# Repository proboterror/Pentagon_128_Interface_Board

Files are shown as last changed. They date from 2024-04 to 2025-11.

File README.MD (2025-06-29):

# Интерфейсная плата разъемов для Pentagon 128 2023/2024

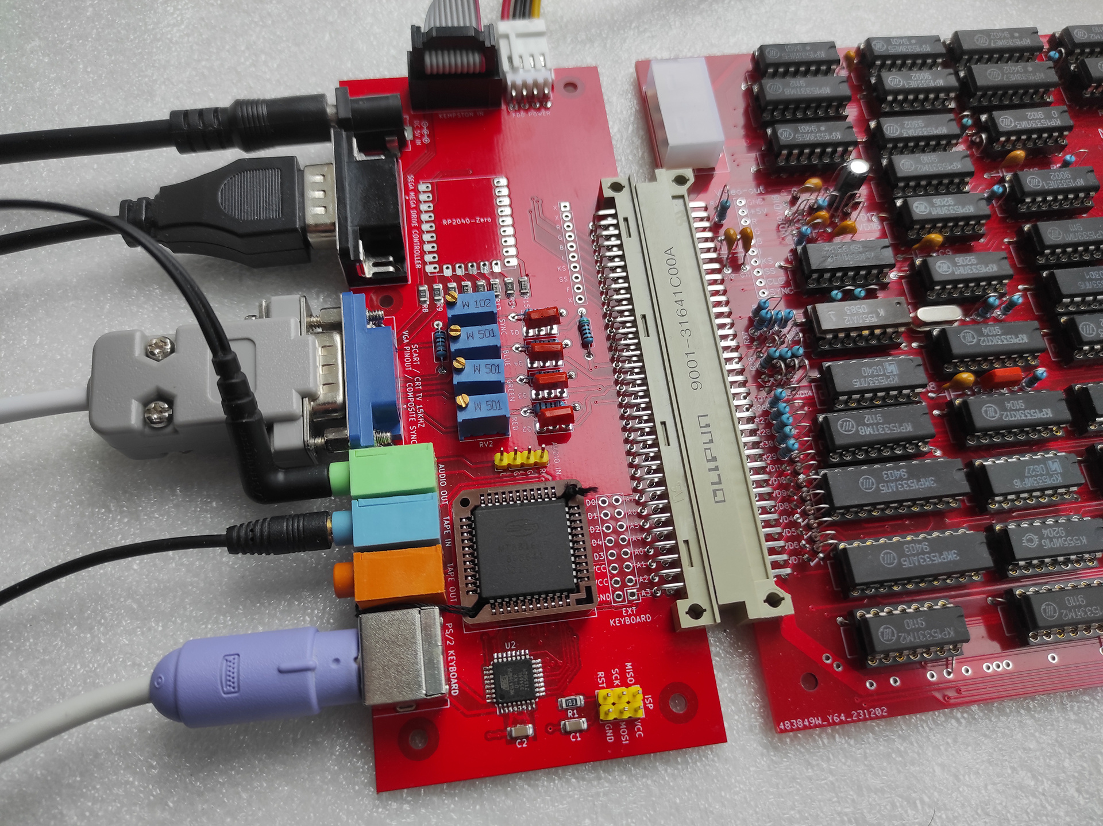
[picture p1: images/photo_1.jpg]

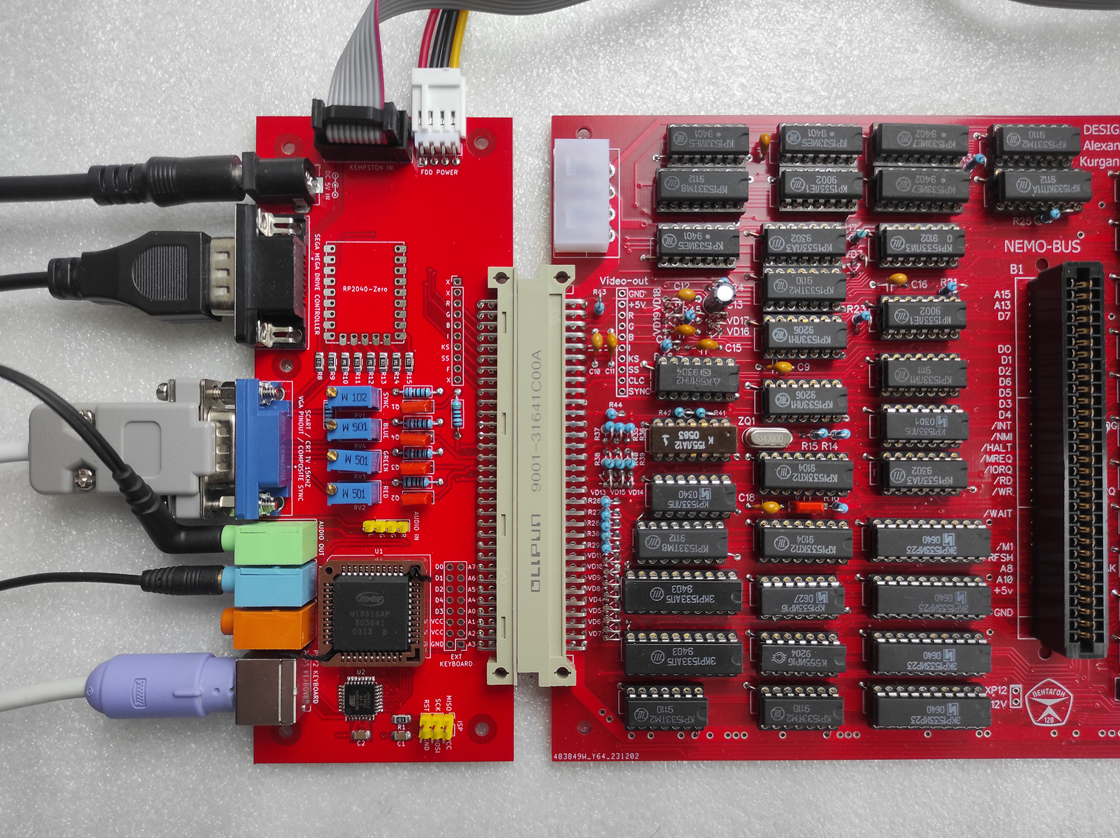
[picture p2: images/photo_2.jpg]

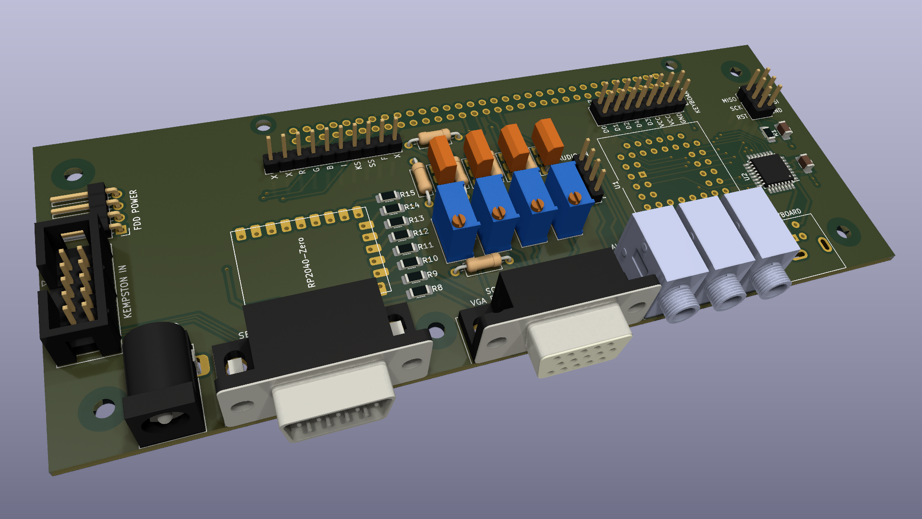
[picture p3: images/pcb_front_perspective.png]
pcb_front_perspective

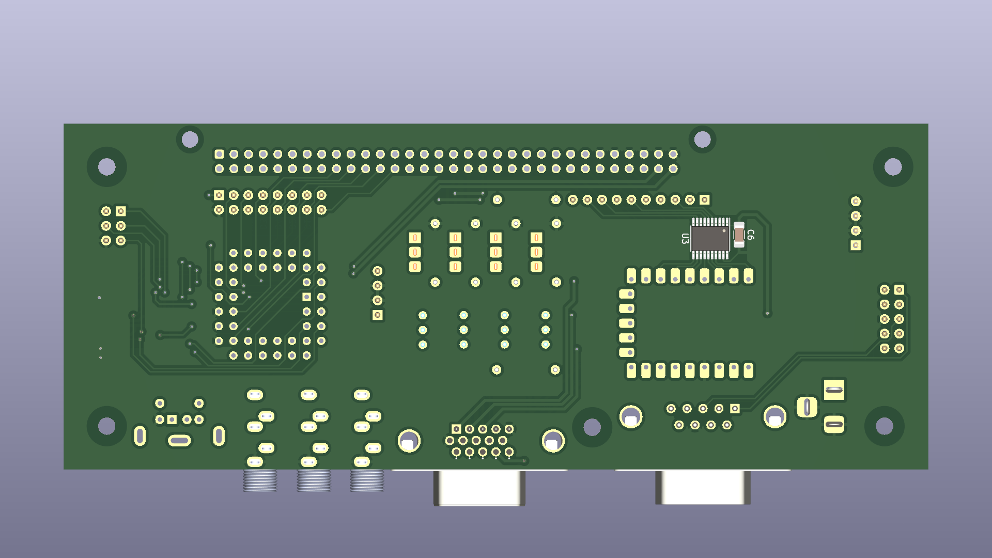
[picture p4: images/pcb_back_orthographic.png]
pcb_back_orthographic

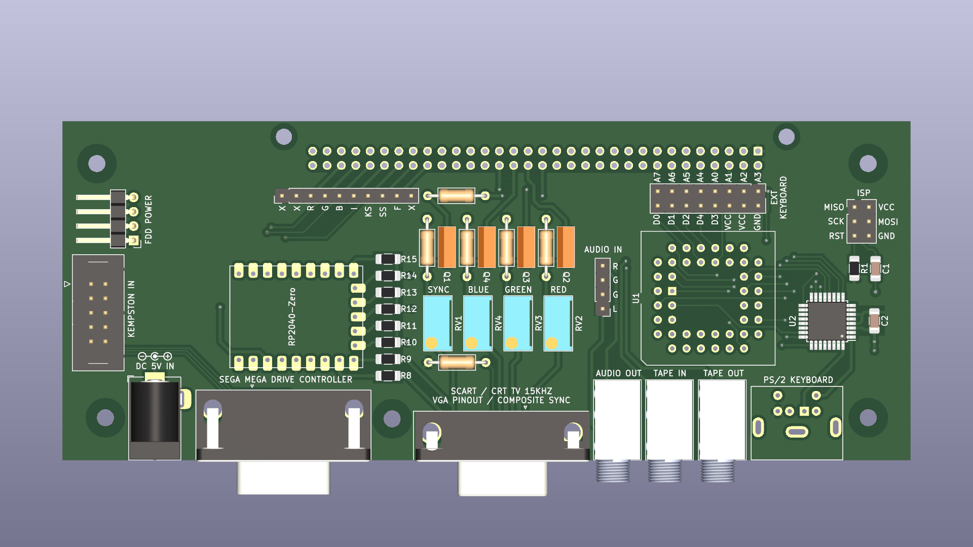
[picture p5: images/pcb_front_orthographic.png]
pcb_front_orthographic

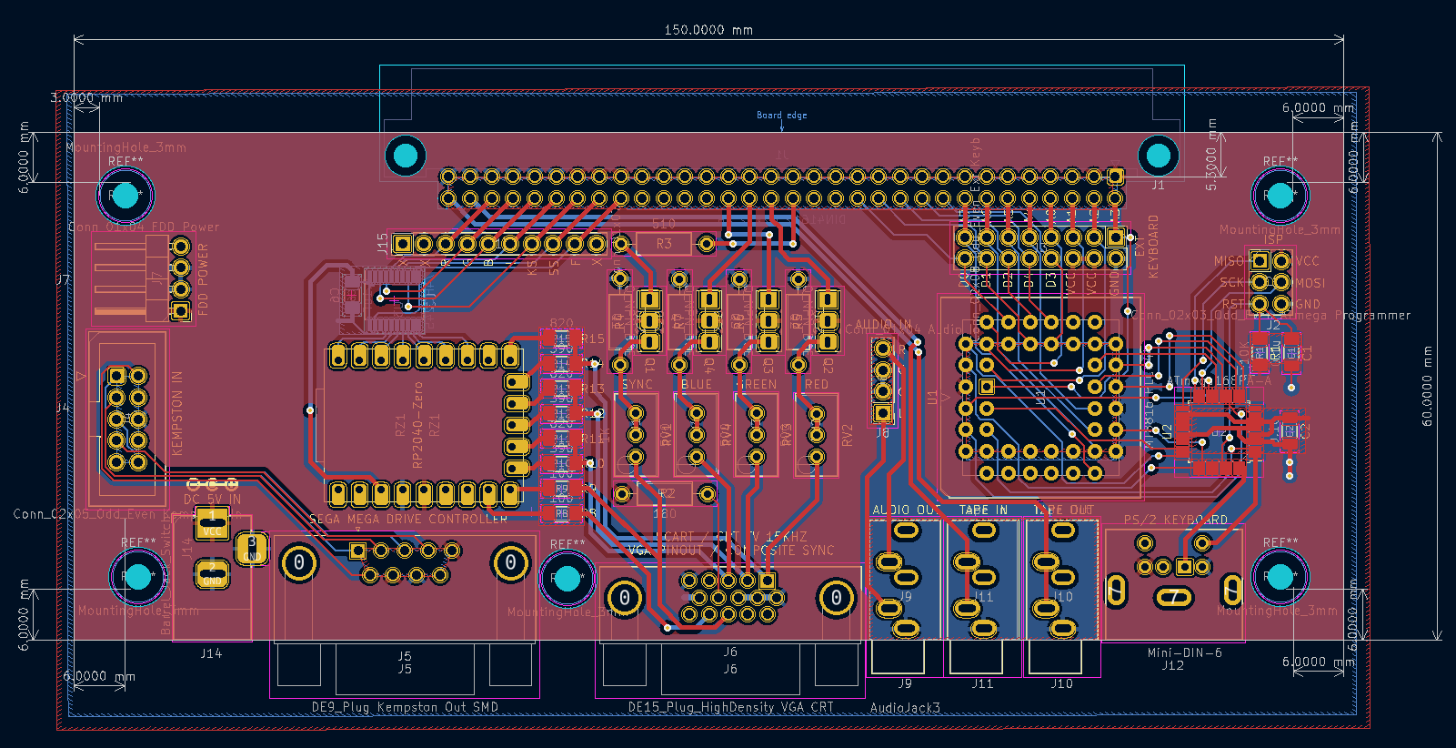
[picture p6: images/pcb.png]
pcb

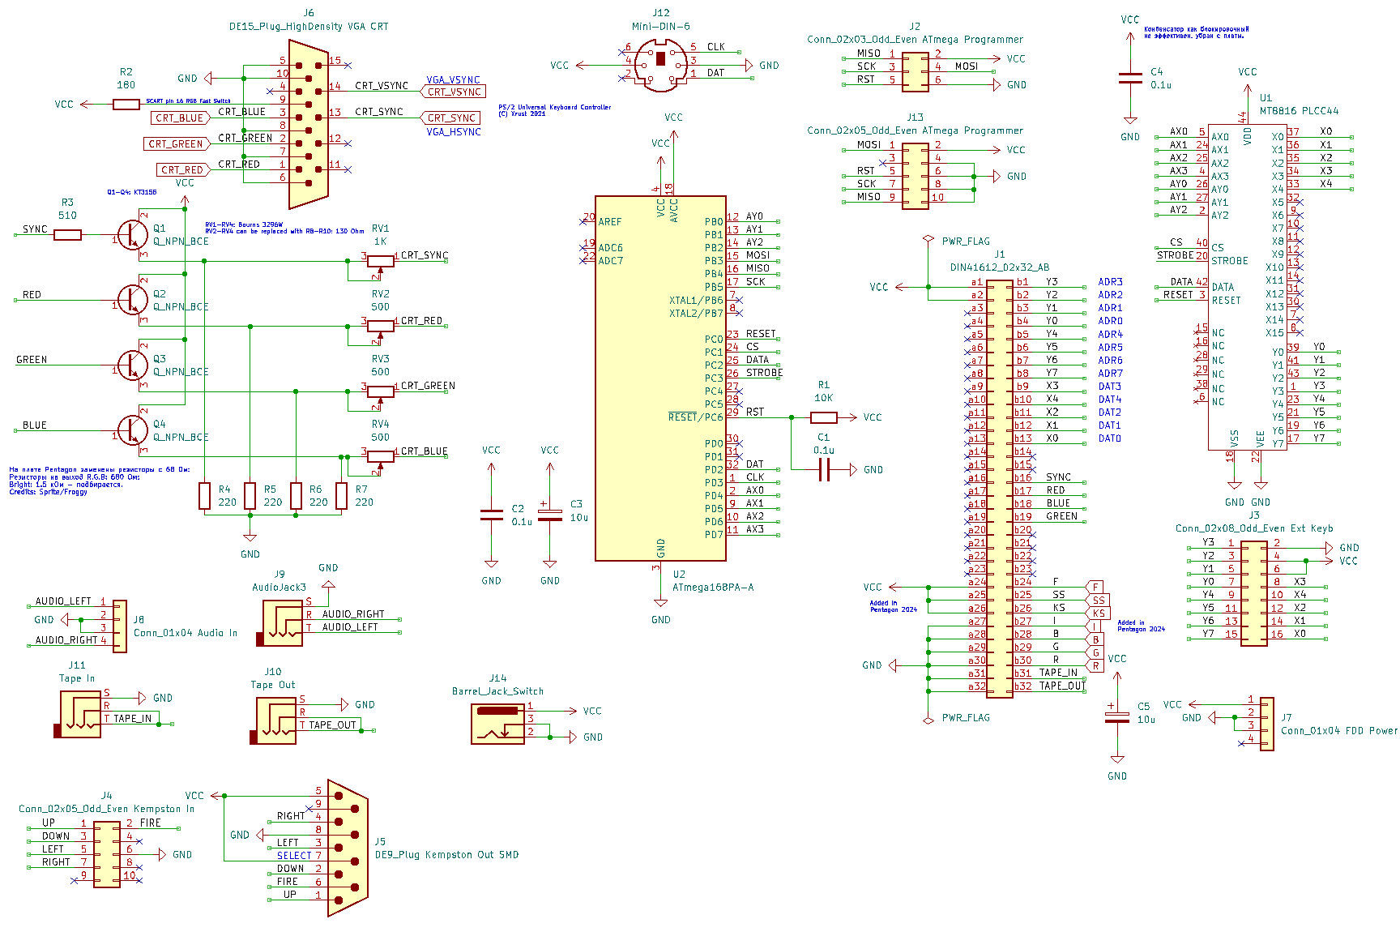
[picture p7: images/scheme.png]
scheme

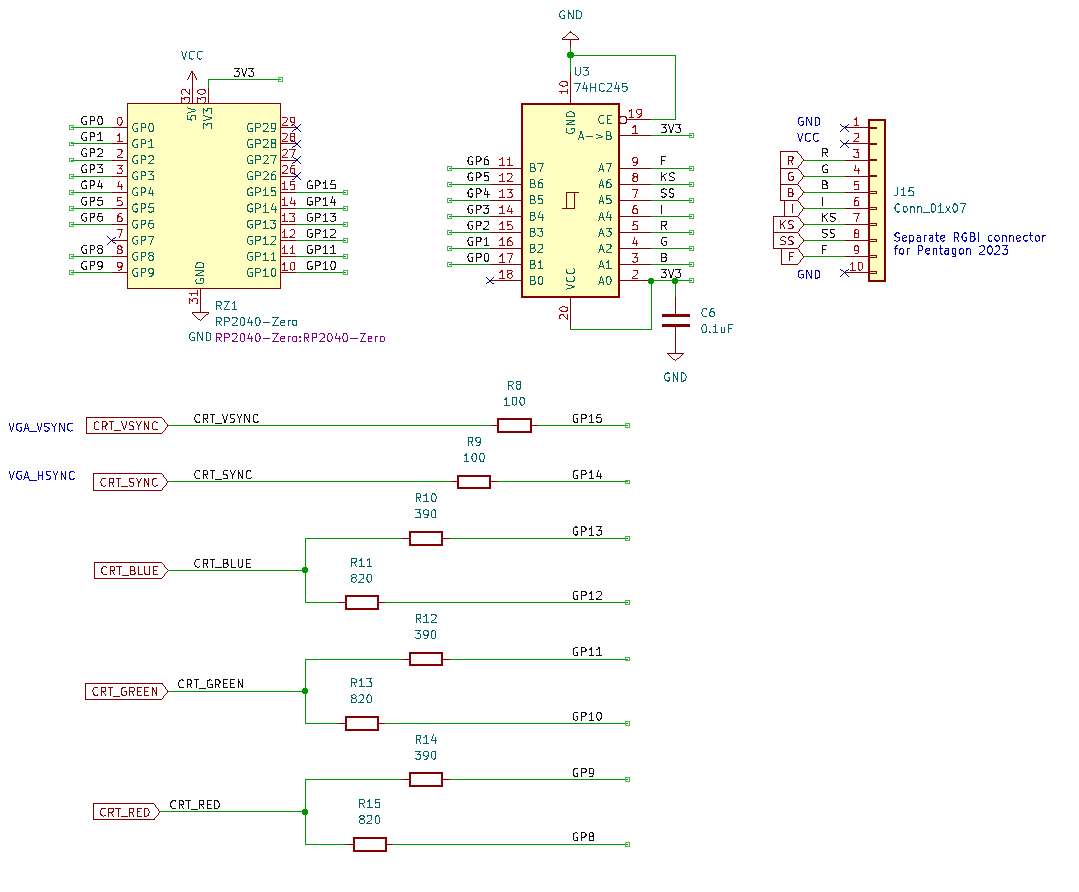
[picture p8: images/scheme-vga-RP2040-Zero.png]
scheme-vga


Плата основывается на открытых проектах и информации:
* [PS/2 Universal Keyboard Controller](https://zx-pk.ru/threads/33211-universalnyj-kontroller-ps-2-klaviatury-dlya-kompyuterov-s-matrichnymi-klaviaturami.html) (C) Xrust 2021
* Схема согласования SCART TV-Out: Sprite @tg / Froggy @zx-pk.ru
* [ZX_RGBI2VGA-HDMI](https://github.com/AlexEkb4ever/ZX_RGBI2VGA-HDMI) (C) @Alex_Eburg 

## Входные требования:
Нужно разработать и изготовить плату интерфейсных разъемов для Pentagon 2023/2024.<br>
Плата подсоединяется слева к системному разъему.
* Выход на 15 KHz CRT TV/монитор с разъемом SCART RGB, звук на SCART не выводится.
* Контроллер PS/2 клавиатуры. Оставить возможность подсоединить внешнюю расширенную клавиатуру на матрице контактов.
* Вход для подключения Sega Mega Drive геймпада как Kempston.
* Разъем Floppy Power 5V.
* Разъем питания DC IN 5V (5.5x2.1mm) для подсоединения внешного блока питания без переходника.
* Разъем Audio Out стандартный stereo mini jack 3.5 mm.
* Разъем Tape In mono 3.5 mm.
* Разъем Tape Out mono 3.5 mm.
* Без МГТФ.

Недостающие на системном разъемы сигналы Audio Out и Kempston прокидываются стандартными шлейфами / кабелями.

Не входит в требования:
* Возможность размещения платы позади основной платы, а не слева. Тем не менее, это возможно, если запаять на основной и интерфейсной плате угловые разъемы "гребенкой" (pin header) и соединить их шлейфами.
* Выход на мониторы VGA 31 KHz, HDMI 720p
* Размещение beeper'а

## Детали реализации:
Для проектирования использовался KiCad 7.<br>
Размеры платы 150x60 мм.

### Выбор краевого разъема:<br>
Было желание использовать дешевые двухрядные 2.54 mm angle 2x32 pin header'ы. Увы, female разъемы на 2x32 pin в природе пока не обнаружены.<br>
Придется использовать DIN 41612.<br>
На известном китайском сайте комплект male+female 420 р.<br>

### TV Out:
В качестве разъема выхода на SCART использован трехрядный разъем DB15 в стандартной VGA распиновке.<br>
Это позволяет использовать стандартные кабели VGA-SCART или VGA-BNC, предназначенные для PC [СRTEmuDriver](http://geedorah.com/eiusdemmodi/forum/viewtopic.php?id=295) / присоединить к OSSC стандартным VGA кабелем / поэкспериментировать с некоторыми ЖК мониторами.<br>
Композитная синхронизация выведена на пин 13 (HSYNC).<br>
Опциональный раздельный вывод HSYNC/VSYNC рассматривался, но не реализован.<br>
На пин 9 (в VGA E-DDC +5V) выведено напряжение питания 5V через резистор 180 ом для удобства переключения TV в режим SCART RGB (SCART pin 16 Fast Switch).<br>
По стандарту SCART входное сопротивление на пинах RGBS 75 ом, размах сигналов RGB 0.7V, SYNC (Video In) 1V. На практике же может потребоваться подстройка уровня SYNC.<br>

На плате Pentagon заменены резисторы с 68 Ом:<br>
Резисторы на выход R,G,B: 680 Ом;<br>
Bright: 1.5 кОм - подбирается.<br>
Схему согласования и номиналы предоставил Sprite/Froggy.<br>

После некоторых сомнений заменены выходные резисторы 130 Ом сигналов RGB интерфейсной платы на подстроечные, т.к. не все телевизоры созданы одинаковыми.<br>

### Gamepad:
Подробнее по нюансам подключению Sega Mega Drive геймпада:<br>
https://t.me/Pentagon_ZX_Chat/122617

### PS/2 и обычная клавиатура:
[Контроллер клавиатуры PS/2 Universal Keyboard Controller (C) Xrust 2021](
https://zx-pk.ru/threads/33211-universalnyj-kontroller-ps-2-klaviatury-dlya-kompyuterov-s-matrichnymi-klaviaturami.html)<br>
Схема на мой взгляд идеологически верная, т.к. не использует wait и в принципе не зависит от скорости контроллера.<br>
Выбрана матрица ключей MT8816 в корпусе PLCC, т.к. она компактнее. Устанавливается в панельку для упрощения монтажа и демонтажа, если будет конфликт с матричной клавиатурой. 

На плате разведен разъем под подключение стандартной матричной клавиатуры.<br>
Отдаленном будущем планируется разработать плату расширенной клавиатуры на современных переключателях, с разъемом сигналов слева специально для Pentagon.<br>
Сейчас можно подключить например [клавиатуру от A.V.P.](https://github.com/AlexPodlesnov/ZX-Clone-Delta-C-mechanical-keyboard)

## Известные проблемы:
* При размещении дисковода (GOTEK) справа нужно тянуть кабель питания от интерфейсной платы длиной около 50 см.
* Доступные в продаже готовые кабели длиной до 30 см, очень редко 50 см. Было бы удобнее, если бы разъем питания дисковода остался на основной плате.
* Разъем Audio Out находится близко к разъему TV Out. Штекер наушников диаметром больше 8 мм - не поместится.
* Порядок рядов контактов a/b DIN 41612 отличается от СНП58. Также в дизайне платы пришлось перевернуть female разъем на нижнюю часть платы для корректной нумерации контактов. Размещаться он будет на верхней стороне платы.

## Сомнительно:
* На плате Pentagon 2024 выведено 5 пинов VCC, 6 пинов GND. На плате Pentagon 2023 выведено 2 пина VCC, 6 пинов GND. Не будет работать основная плата стабильно от питания через системный разъем - придется использовать Molex разъем питания.
* А не будут ли выходы ключей MT8816 в состоянии "0" конфликтовать с внешней клавиатурой?
* Нет блокировочного конденсатора на MT8816
* Для ATMEGA168 блокировочные конденсаторы желательны на каждый вход питания отдельно
* Электролитические конденсаторы большой емкости на питание убраны
* Mounting Holes без металлизации

## Bill of materials
На плате Pentagon заменены резисторы с 68 Ом:<br>
Резисторы на выход R,G,B: 680 Ом;<br>
Bright: 1.5 кОм - подбирается при необходимости.

U2 ATMEGA168PA-AU TQFP-32<br>
U1 MT8816AP PLCC-44<br>
PLCC-44 IC DIP socket

C1, C2 Capacitor_SMD:C_1206_3216Metric 0.1u

Q1, Q2, Q3, Q4 Транзистор К315Б x4

RV1 Bourns 3296W Potentiometer 1K Ohm<br>
[aliexpress](https://aliexpress.ru/item/32845414733.html?sku_id=65244516762)<br>
RV2, RV3, RV4 Bourns 3296W Potentiometer 500 Ohm<br>
[aliexpress](https://aliexpress.ru/item/32845414733.html?sku_id=65244516761)

R3 Resistor 0.25W R_Axial_DIN0207_L6.3mm_D2.5mm_P10.16mm 510R<br>
R4, R5, R6, R7 Resistor 0.25W R_Axial_DIN0207_L6.3mm_D2.5mm_P10.16mm 220R<br>
R2 Resistor 0.25W R_Axial_DIN0207_L6.3mm_D2.5mm_P10.16mm 180R

R1 Resistor_SMD:R_206_3216Metric 10K

### Разъемы:
J1<br>
Connector DIN 41612 Dual Row 64 Pin Male Female Pitch 2.54mm 2x32<br>
OUPIIN 9001-31641C00A (DIN 41612-64AB-MR)<br>
OUPIIN 9001-34641C00A (DIN 41612-64AB-FR)<br>
[aliexpress](https://aliexpress.com/item/4000215552439.html)

J4 Connector_IDC:IDC-Header_2x05_P2.54mm_Vertical<br>
[aliexpress](https://aliexpress.ru/item/1005004266492521.html?sku_id=12000028572172233)

J5 DSUB-9_Male_Horizontal_P2.77x2.84mm_EdgePinOffset7.70mm_Housed_MountingHolesOffset9.12mm<br>
[aliexpress](https://aliexpress.ru/item/32845329350.html?sku_id=12000028099335636)<br>
J6 DSUB-15-HD_Female_Horizontal_P2.29x1.98mm_EdgePinOffset3.03mm_Housed_MountingHolesOffset4.94mm<br>
[aliexpress](https://aliexpress.ru/item/32747020225.html?sku_id=61784388444)

J7 Floppy Power 4 Pin 2.54 mm Right Angle Connector<br>
[aliexpress](https://aliexpress.ru/item/1005006171641179.html?sku_id=12000036108671633)<br>
Подбирайте High / Flat вариант под вашу ревизию платы. Длина варианта High: 12 мм, Flat: 10 мм.

J9, J10, J11<br>
10PCS PJ-215 PJ-325 3.5MM Headphone jack 5Pin Female Socket Connector for Audio Video RED BLACK BLUE YELLOW GREEN<br>
[aliexpress](https://aliexpress.com/item/32830267803.html)

J12 Mini DIN 6 Female<br>
[aliexpress](https://aliexpress.ru/item/4000106967115.html?sku_id=10000000276404455)

J14<br>
PCB Mount 5.5 x 2.1 mm Female DC Power Connector<br>
[aliexpress](https://aliexpress.ru/item/32951864536.html)

## Сборка прошивки
В Arduino IDE:<br>
Открыть source/ATmega/Spectrum128.ino

Установить через Tools/Manage Libraries библиотеку [PS2KeyRaw](https://github.com/techpaul/PS2KeyRaw)<br>
Установить [MiniCore](https://github.com/MCUdude/MiniCore#how-to-install)

Выбрать Tools/Board/MiniCore/ATmega168<br>
Clock: Internal 8 MHz<br>
Variant: 168P / 168PA 

Sketch/Verify/Compile<br>
Sketch/Export compiled Binary

[Скомпилированная прошивка](source/ATmega/Spectrum128.ino_atmega168p_8000000L.hex)

## Заливка прошивки
При наличии совместимых программатора и bootloader'а в контроллере прошить можно прямо из Aduino IDE.

Также для прошивки ATmega можно использовать программатор CH341A и ПО NeoProgrammer V2.2.

[Fuses для прошивки ATmega168PA:](source/ATmega/fuses.png)
<pre>
Low     High    Extended
0xE2    0xDF    0x*F9
</pre>

## Замечания после сборки платы:
* После поключения к телевизору через SCART нет картинки. Нужно подстроить переменный резистор SYNC.
* Клавиатура PS/2 работает.
* Геймпад Sega Mega Drive работает как Kempston (нужен кабель FC 2x5 10pin 30 см.).
* Audio Out работает (нужен кабель, например от CDROM Audio 40-60 см.).
* Tape In работает (использовался кабель jack 3.5mm - jack 3.5mm и смартфон).
* В моем случае в новой ATmega168 были прошиты fuses на использование внешнего кварца, соответственно контроллер не работал и не прошивался. Решилось припайкой кварца на 8 MHz к ногам контроллера на время прошивки fuses.
* Размер прошивки позволяет использовать ATmega8A.

При подключении питания через разъем DC IN 5V (5.5x2.1mm) плата Пентагона работает стабильно, измеримого падения напряжения нет. Рекомендуемый блок питания MEAN WELL GST60A05-P1J 5V 6A 30W.

## Пока не проверялось:
После финализации платы на ней остался задел по свободному месту.

Для экспериментов добавлен интерфейс VGA на Raspberry Pi Pico по схеме @Alex_Eburg [ZX_RGBI2VGA-HDMI](https://github.com/AlexEkb4ever/ZX_RGBI2VGA-HDMI)<br>
Для полноразмерной зеленой платы Pico места нет, использована RP2040-Zero от Waveshare.<br>
Отдельная плата адаптера на RP2040-Zero отлично работает в VGA разрешениях вплоть до 1280x1024 с прошивкой [zx-rgbi-to-vga-hdmi_gotek-osd](https://github.com/proboterror/zx-rgbi-to-vga-hdmi_gotek-osd).<br>
Сверху можно добавить разъем на 2 контакта для GOTEK OSD.<br>
Отключение питания +5V при USB подключении не предусмотрено, также разъем Kempston может блокировать доcтуп к USB.

Одновременно на плате может быть подключен либо CRT TV/SCART выход либо VGA.

На Pentagon 2024 сигналы RGBI для интерфейса выведены на системный разъем, для Pentagon 2023 можно прокинуть с разъема на плате коротким шлейфом.

### BoM:
RZ1 RP2040-Zero (Waveshare)<br>
U3 74HC245 TSSOP-20_4.4x6.5mm_P0.65mm

R8, R9 Resistor SMD 1206 100R x2<br>
R10, R12, R14 Resistor SMD 1206 390R x3<br>
R11, R13, R15 Resistor SMD 1206 820R x3

C6 Capacitor SMD 1206 0.1uF

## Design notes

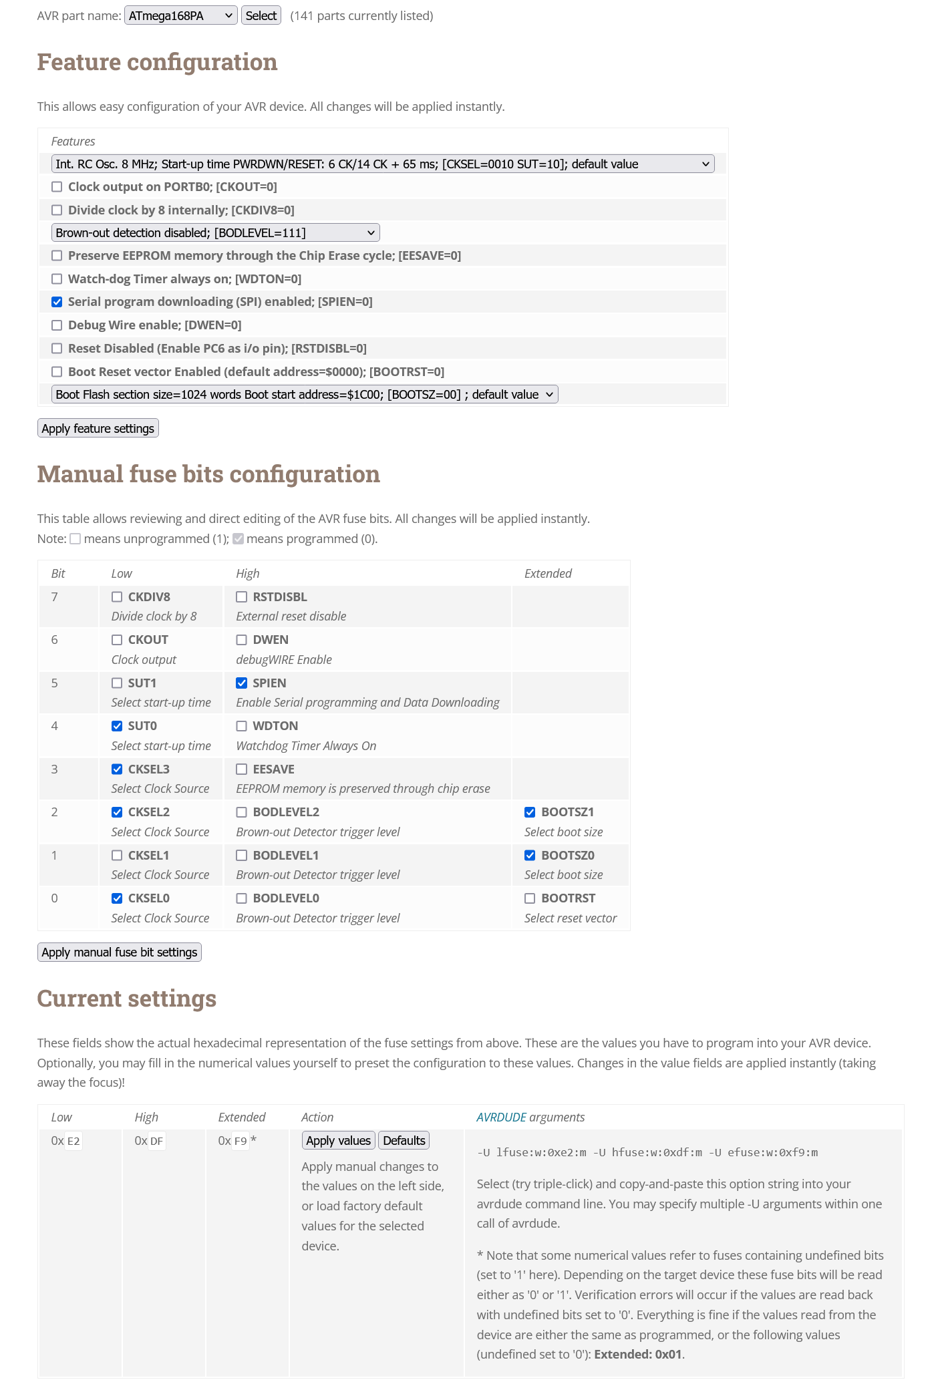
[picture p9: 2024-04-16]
source/ATmega/fuses.png

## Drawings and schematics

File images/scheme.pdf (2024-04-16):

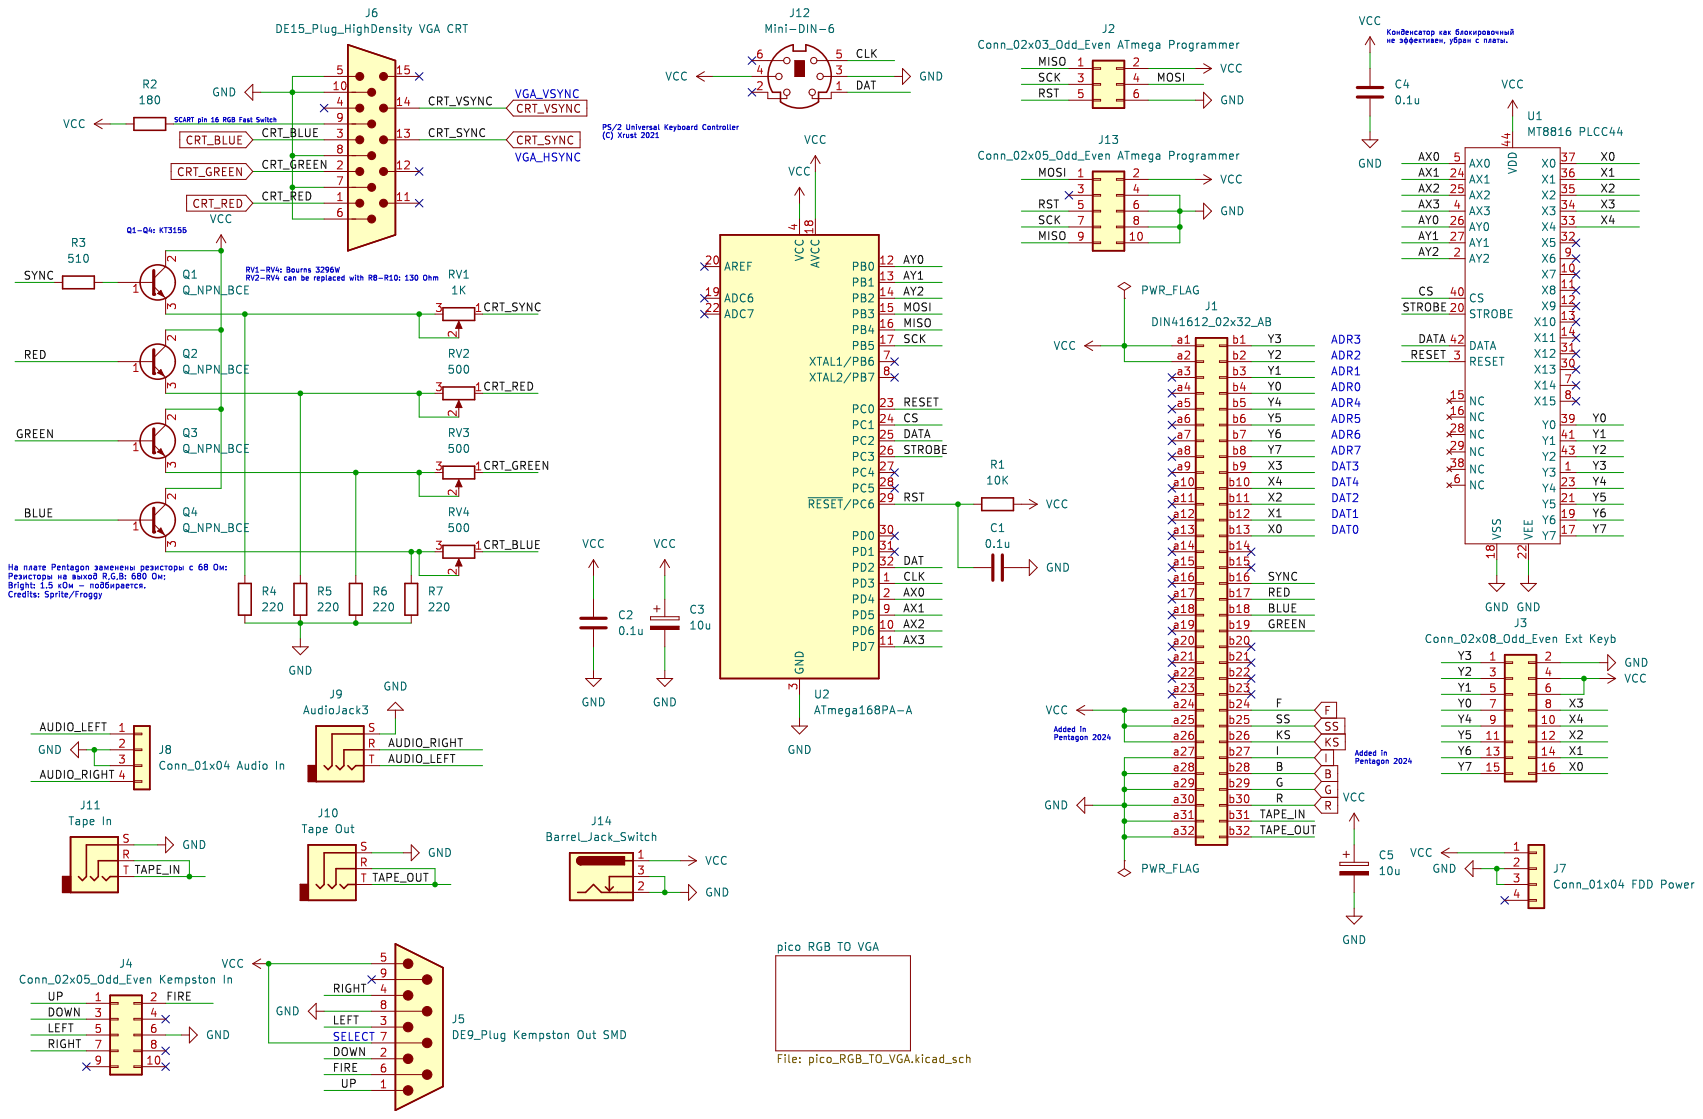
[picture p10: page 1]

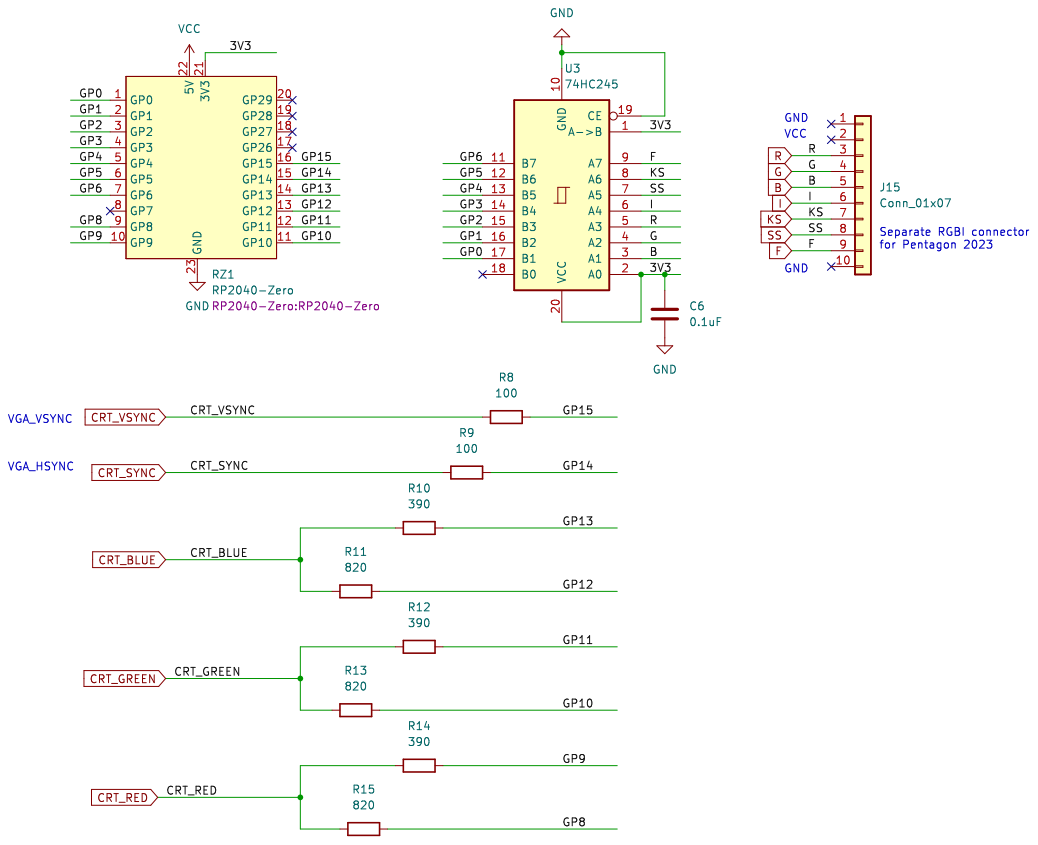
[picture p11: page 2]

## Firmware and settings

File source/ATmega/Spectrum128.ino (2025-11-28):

#include <PS2KeyRaw.h>

#define AX0 4
#define AX1 5
#define AX2 6
#define AX3 7
#define AY0 8
#define AY1 9
#define AY2 10
#define RSTMT 14
#define CSMT  15
#define DATMT 16
#define STBMT 17
#define DATAPIN 2
#define IRQPIN  3

/*
ZX Spectrum 40-key keyboard matrix:
         ┌─────────────────────────────────────────────────────┐
         │     ┌─────────────────────────────────────────┐     │
         │     │     ┌─────────────────────────────┐     │     │
         │     │     │     ┌─────────────────┐     │     │     │
         │     │     │     │     ┌─────┐     │     │     │     │
       ┌─┴─┐ ┌─┴─┐ ┌─┴─┐ ┌─┴─┐ ┌─┴─┐ ┌─┴─┐ ┌─┴─┐ ┌─┴─┐ ┌─┴─┐ ┌─┴─┐
 A11/ ─┤ 1 ├─┤ 2 ├─┤ 3 ├─┤ 4 ├─┤ 5 │ │ 6 ├─┤ 7 ├─┤ 8 ├─┤ 9 ├─┤ 0 ├─ A12/
       └─┬─┘ └─┬─┘ └─┬─┘ └─┬─┘ └─┬─┘ └─┬─┘ └─┬─┘ └─┬─┘ └─┬─┘ └─┬─┘
       ┌─┴─┐ ┌─┴─┐ ┌─┴─┐ ┌─┴─┐ ┌─┴─┐ ┌─┴─┐ ┌─┴─┐ ┌─┴─┐ ┌─┴─┐ ┌─┴─┐
 A10/ ─┤ Q ├─┤ W ├─┤ E ├─┤ R ├─┤ T │ │ Y ├─┤ U ├─┤ I ├─┤ O ├─┤ P ├─ A13/
       └─┬─┘ └─┬─┘ └─┬─┘ └─┬─┘ └─┬─┘ └─┬─┘ └─┬─┘ └─┬─┘ └─┬─┘ └─┬─┘
       ┌─┴─┐ ┌─┴─┐ ┌─┴─┐ ┌─┴─┐ ┌─┴─┐ ┌─┴─┐ ┌─┴─┐ ┌─┴─┐ ┌─┴─┐ ┌─┴─┐
  A9/ ─┤ A ├─┤ S ├─┤ D ├─┤ F ├─┤ G │ │ H ├─┤ J ├─┤ K ├─┤ L ├─┤Ent├─ A14/
       └─┬─┘ └─┬─┘ └─┬─┘ └─┬─┘ └─┬─┘ └─┬─┘ └─┬─┘ └─┬─┘ └─┬─┘ └─┬─┘
       ┌─┴─┐ ┌─┴─┐ ┌─┴─┐ ┌─┴─┐ ┌─┴─┐ ┌─┴─┐ ┌─┴─┐ ┌─┴─┐ ┌─┴─┐ ┌─┴─┐
  A8/ ─┤ CS├─┤ Z ├─┤ X ├─┤ C ├─┤ V │ │ B ├─┤ N ├─┤ M ├─┤ SS├─┤ SP├─ A15/
       └─┬─┘ └─┬─┘ └─┬─┘ └─┬─┘ └─┬─┘ └─┬─┘ └─┬─┘ └─┬─┘ └─┬─┘ └─┬─┘
         D0    D1    D2    D3    D4    D4    D3    D2    D1    D0

ZX Spectrum+ extended 58 keys keyboard:
 CS + 1 "EDIT"
 CS + 2 "CAPS LOCK"
 CS + 3 "TRUE VIDEO"
 CS + 4 "INV VIDEO"
 CS + 5 "LEFT"
 CS + 6 "DOWN"
 CS + 7 "UP"
 CS + 8 "RIGHT"
 CS + 9 "GRAPH"
 CS + 0 "DELETE"

 CS + SP "BREAK"
 CS + SS "EXTENDED MODE"

 SS + N ","
 SS + M "."
 SS + O ";"
 SS + P """
*/

/*
8x16 Analog Switch Array MT8816

The following table is the decoding truth table of the 7-bit address for MT8816 chip and the address table of 128 analog switches.

Intersection
Point                                                    Address
Port Y -        AY2   AY1   AY0   AX3   AX2   AX1   AX0    No.
Port X
Y0 - X0          0     0     0     0     0     0     0     00H
Y0 - X1          0     0     0     0     0     0     1     01H
Y0 - X2          0     0     0     0     0     1     0     02H
······
Y7 - X14         1     1     1     1     1     1     0     7EH
Y7 - X15         1     1     1     1     1     1     1     7FH

ZX Spectrum A8..A15 bus connected to MT8816 Y0..Y7 pins; D0..D4 bus connected to MT8816 X0..X4 pins.
*/
enum MT8816_AX
{
	D0 = 0,
	D1 = 1,
	D2 = 2,
	D3 = 3,
	D4 = 4
};

enum MT8816_AY
{
	A_8  = 0 << 4,
	A_9  = 1 << 4,
	A_10 = 2 << 4,
	A_11 = 3 << 4,
	A_12 = 4 << 4,
	A_13 = 5 << 4,
	A_14 = 6 << 4,
	A_15 = 7 << 4
};

enum zx_keys
{
	ZX_KEY_CS  = D0 | A_8,
	ZX_KEY_A   = D0 | A_9,
	ZX_KEY_Q   = D0 | A_10,
	ZX_KEY_1   = D0 | A_11,
	ZX_KEY_0   = D0 | A_12,
	ZX_KEY_P   = D0 | A_13,
	ZX_KEY_ENT = D0 | A_14,
	ZX_KEY_SP  = D0 | A_15,
	ZX_KEY_Z   = D1 | A_8,
	ZX_KEY_S   = D1 | A_9,
	ZX_KEY_W   = D1 | A_10,
	ZX_KEY_2   = D1 | A_11,
	ZX_KEY_9   = D1 | A_12,
	ZX_KEY_O   = D1 | A_13,
	ZX_KEY_L   = D1 | A_14,
	ZX_KEY_SS  = D1 | A_15,
	ZX_KEY_X   = D2 | A_8,
	ZX_KEY_D   = D2 | A_9,
	ZX_KEY_E   = D2 | A_10,
	ZX_KEY_3   = D2 | A_11,
	ZX_KEY_8   = D2 | A_12,
	ZX_KEY_I   = D2 | A_13,
	ZX_KEY_K   = D2 | A_14,
	ZX_KEY_M   = D2 | A_15,
	ZX_KEY_C   = D3 | A_8,
	ZX_KEY_F   = D3 | A_9,
	ZX_KEY_R   = D3 | A_10,
	ZX_KEY_4   = D3 | A_11,
	ZX_KEY_7   = D3 | A_12,
	ZX_KEY_U   = D3 | A_13,
	ZX_KEY_J   = D3 | A_14,
	ZX_KEY_N   = D3 | A_15,
	ZX_KEY_V   = D4 | A_8,
	ZX_KEY_G   = D4 | A_9,
	ZX_KEY_T   = D4 | A_10,
	ZX_KEY_5   = D4 | A_11,
	ZX_KEY_6   = D4 | A_12,
	ZX_KEY_Y   = D4 | A_13,
	ZX_KEY_H   = D4 | A_14,
	ZX_KEY_B   = D4 | A_15,

	ZX_KEY_NONE= 0x7F
};

/*
 Reference:
 The PS/2 Keyboard Interface
 Source: http://www.Computer-Engineering.org/ps2keyboard/
 Author: Adam Chapweske
 Keyboard Scan Codes: Set 2

 Notes for PS/2 keyboard scan codes set 2 (default):

 - Following keys hame multi-byte scan codes:
  Key         Make Code   Break Code
  L GUI       E0,1F       E0,F0,1F
  R CTRL      E0,14       E0,F0,14
  R GUI       E0,27       E0,F0,27
  R ALT       E0,11       E0,F0,11
  APPS        E0,2F       E0,F0,2F
  PRNT SCRN   E0,12,      E0,F0,7C,
              E0,7C       E0,F0,12
  PAUSE       E1,14,77,
              E1,F0,14,   -NONE-
              F0,77
  INSERT      E0,70       E0,F0,70
  HOME        E0,6C       E0,F0,6C
  PG UP       E0,7D       E0,F0,7D
  DELETE      E0,71       E0,F0,71
  END         E0,69       E0,F0,69
  PG DN       E0,7A       E0,F0,7A
  U ARROW     E0,75       E0,F0,75
  L ARROW     E0,6B       E0,F0,6B
  D ARROW     E0,72       E0,F0,72
  R ARROW     E0,74       E0,F0,74
  KP /        E0,4A       E0,F0,4A
  KP EN       E0,5A       E0,F0,5A

 - Pause/Break key does not have a break code

 ACPI Scan Codes:
  Key   Make   Break
  Power E0,37  E0,F0,37
  Sleep E0,3F  E0,F0,3F
  Wake  E0,5E  E0,F0,5E

 Windows Multimedia Scan Codes:
  Key            Make   Break
  Next Track     E0,4D  E0,F0,4D
  Previous Track E0,15  E0,F0,15
  Stop           E0,3B  E0,F0,3B
  Play/Pause     E0,34  E0,F0,34
  Mute           E0,23  E0,F0,23
  Volume Up      E0,32  E0,F0,32
  Volume Down    E0,21  E0,F0,21
  Media Select   E0,50  E0,F0,50
  E-Mail         E0,48  E0,F0,48
  Calculator     E0,2B  E0,F0,2B
  My Computer    E0,40  E0,F0,40
  WWW Search     E0,10  E0,F0,10
  WWW Home       E0,3A  E0,F0,3A
  WWW Back       E0,38  E0,F0,38
  WWW Forward    E0,30  E0,F0,30
  WWW Stop       E0,28  E0,F0,28
  WWW Refresh    E0,20  E0,F0,20
  WWW Favorites  E0,18  E0,F0,18
*/

enum ps2_scan_codes_set_2
{
//                     PS/2 SET 2, PS/2 SET 1 (XT/BIOS PC)
	PS2_KEY_ESCAPE       = 0x76 /*0x01*/,
	PS2_KEY_1            = 0x16 /*0x02*/,
	PS2_KEY_2            = 0x1E /*0x03*/,
	PS2_KEY_3            = 0x26 /*0x04*/,
	PS2_KEY_4            = 0x25 /*0x05*/,
	PS2_KEY_5            = 0x2E /*0x06*/,
	PS2_KEY_6            = 0x36 /*0x07*/,
	PS2_KEY_7            = 0x3D /*0x08*/,
	PS2_KEY_8            = 0x3E /*0x09*/,
	PS2_KEY_9            = 0x46 /*0x0A*/,
	PS2_KEY_0            = 0x45 /*0x0B*/,
	PS2_KEY_MINUS        = 0x4E /*0x0C*/, // - on main keyboard
	PS2_KEY_EQUALS       = 0x55 /*0x0D*/,
	PS2_KEY_BACK         = 0x66 /*0x0E*/, // backspace
	PS2_KEY_TAB          = 0x0D /*0x0F*/,
	PS2_KEY_Q            = 0x15 /*0x10*/,
	PS2_KEY_W            = 0x1D /*0x11*/,
	PS2_KEY_E            = 0x24 /*0x12*/,
	PS2_KEY_R            = 0x2D /*0x13*/,
	PS2_KEY_T            = 0x2C /*0x14*/,
	PS2_KEY_Y            = 0x35 /*0x15*/,
	PS2_KEY_U            = 0x3C /*0x16*/,
	PS2_KEY_I            = 0x43 /*0x17*/,
	PS2_KEY_O            = 0x44 /*0x18*/,
	PS2_KEY_P            = 0x4D /*0x19*/,
	PS2_KEY_LBRACKET     = 0x54 /*0x1A*/,
	PS2_KEY_RBRACKET     = 0x5B /*0x1B*/,
	PS2_KEY_RETURN       = 0x5A /*0x1C*/, // Enter on main keyboard
	PS2_KEY_LCONTROL     = 0x14 /*0x1D*/,
	PS2_KEY_A            = 0x1C /*0x1E*/,
	PS2_KEY_S            = 0x1B /*0x1F*/,
	PS2_KEY_D            = 0x23 /*0x20*/,
	PS2_KEY_F            = 0x2B /*0x21*/,
	PS2_KEY_G            = 0x34 /*0x22*/,
	PS2_KEY_H            = 0x33 /*0x23*/,
	PS2_KEY_J            = 0x3B /*0x24*/,
	PS2_KEY_K            = 0x42 /*0x25*/,
	PS2_KEY_L            = 0x4B /*0x26*/,
	PS2_KEY_SEMICOLON    = 0x4C /*0x27*/,
	PS2_KEY_APOSTROPHE   = 0x52 /*0x28*/,
	PS2_KEY_GRAVE        = 0x0E /*0x29*/, // accent grave
	PS2_KEY_LSHIFT       = 0x12 /*0x2A*/,
	PS2_KEY_BACKSLASH    = 0x5D /*0x2B*/,
	PS2_KEY_Z            = 0x1A /*0x2C*/,
	PS2_KEY_X            = 0x22 /*0x2D*/,
	PS2_KEY_C            = 0x21 /*0x2E*/,
	PS2_KEY_V            = 0x2A /*0x2F*/,
	PS2_KEY_B            = 0x32 /*0x30*/,
	PS2_KEY_N            = 0x31 /*0x31*/,
	PS2_KEY_M            = 0x3A /*0x32*/,
	PS2_KEY_COMMA        = 0x41 /*0x33*/,
	PS2_KEY_PERIOD       = 0x49 /*0x34*/, // . on main keyboard
	PS2_KEY_SLASH        = 0x4A /*0x35*/, // / on main keyboard
	PS2_KEY_RSHIFT       = 0x59 /*0x36*/,
	PS2_KEY_MULTIPLY     = 0x7C /*0x37*/, // * on numeric keypad
	PS2_KEY_LMENU        = 0x11 /*0x38*/, // left Alt
	PS2_KEY_SPACE        = 0x29 /*0x39*/,
	PS2_KEY_CAPITAL      = 0x58 /*0x3A*/,
	PS2_KEY_F1           = 0x05 /*0x3B*/,
	PS2_KEY_F2           = 0x06 /*0x3C*/,
	PS2_KEY_F3           = 0x04 /*0x3D*/,
	PS2_KEY_F4           = 0x0C /*0x3E*/,
	PS2_KEY_F5           = 0x03 /*0x3F*/,
	PS2_KEY_F6           = 0x0B /*0x40*/,
	PS2_KEY_F7           = 0x83 /*0x41*/,
	PS2_KEY_F8           = 0x0A /*0x42*/,
	PS2_KEY_F9           = 0x01 /*0x43*/,
	PS2_KEY_F10          = 0x09 /*0x44*/,
	PS2_KEY_NUMLOCK      = 0x77 /*0x45*/,
	PS2_KEY_SCROLL       = 0x7E /*0x46*/, // Scroll Lock
	PS2_KEY_NUMPAD7      = 0x6C /*0x47*/,
	PS2_KEY_NUMPAD8      = 0x75 /*0x48*/,
	PS2_KEY_NUMPAD9      = 0x7D /*0x49*/,
	PS2_KEY_SUBTRACT     = 0x7B /*0x4A*/, // - on numeric keypad
	PS2_KEY_NUMPAD4      = 0x6B /*0x4B*/,
	PS2_KEY_NUMPAD5      = 0x73 /*0x4C*/,
	PS2_KEY_NUMPAD6      = 0x74 /*0x4D*/,
	PS2_KEY_ADD          = 0x79 /*0x4E*/, // + on numeric keypad
	PS2_KEY_NUMPAD1      = 0x69 /*0x4F*/,
	PS2_KEY_NUMPAD2      = 0x72 /*0x50*/,
	PS2_KEY_NUMPAD3      = 0x7A /*0x51*/,
	PS2_KEY_NUMPAD0      = 0x70 /*0x52*/,
	PS2_KEY_DECIMAL      = 0x71 /*0x53*/, // . on numeric keypad
	PS2_KEY_F11          = 0x78 /*0x57*/,
	PS2_KEY_F12          = 0x07 /*0x58*/
#if 0
	PS2_KEY_NEXTTRACK    = 0xE0, 0x4D /*0x99*/, // Next Track
	PS2_KEY_NUMPADENTER  = 0xE0, 0x5A /*0x9C*/, // Enter on numeric keypad
	PS2_KEY_RCONTROL     = 0xE0, 0x14 /*0x9D*/,
	PS2_KEY_MUTE         = 0xE0, 0x23 /*0xA0*/, // Mute
	PS2_KEY_CALCULATOR   = 0xE0, 0x2B /*0xA1*/, // Calculator
	PS2_KEY_PLAYPAUSE    = 0xE0, 0x34 /*0xA2*/, // Play / Pause
	PS2_KEY_MEDIASTOP    = 0xE0, 0x3B /*0xA4*/, // Media Stop
	PS2_KEY_VOLUMEDOWN   = 0xE0, 0x21 /*0xAE*/, // Volume -
	PS2_KEY_VOLUMEUP     = 0xE0, 0x32 /*0xB0*/, // Volume +
	PS2_KEY_WEBHOME      = 0xE0, 0x3A /*0xB2*/, // Web home
	PS2_KEY_DIVIDE       = 0xE0, 0x4A /*0xB5*/, // / on numeric keypad
	PS2_KEY_SYSRQ        = 0xE0, 0x12, 0xE0, 0x7C /*0xB7*/,
	PS2_KEY_RMENU        = 0xE0, 0x11 /*0xB8*/, // Right Alt
	PS2_KEY_PAUSE        = 0xE1, 0x14, 77, E1, F0, 14, F0, 77 /*0xC5*/, // Pause
	PS2_KEY_HOME         = 0xE0, 0x6C /*0xC7*/, // Home on arrow keypad
	PS2_KEY_UP           = 0xE0, 0x75 /*0xC8*/, // UpArrow on arrow keypad
	PS2_KEY_PRIOR        = 0xE0, 0x7D /*0xC9*/, // PgUp on arrow keypad
	PS2_KEY_LEFT         = 0xE0, 0x6B /*0xCB*/, // LeftArrow on arrow keypad
	PS2_KEY_RIGHT        = 0xE0, 0x74 /*0xCD*/, // RightArrow on arrow keypad
	PS2_KEY_END          = 0xE0, 0x69 /*0xCF*/, // End on arrow keypad
	PS2_KEY_DOWN         = 0xE0, 0x72 /*0xD0*/, // DownArrow on arrow keypad
	PS2_KEY_NEXT         = 0xE0, 0x7A /*0xD1*/, // PgDn on arrow keypad
	PS2_KEY_INSERT       = 0xE0, 0x70 /*0xD2*/, // Insert on arrow keypad
	PS2_KEY_DELETE       = 0xE0, 0x71 /*0xD3*/, // Delete on arrow keypad
	PS2_KEY_LWIN         = 0xE0, 0x1F /*0xDB*/, // Left Windows key
	PS2_KEY_RWIN         = 0xE0, 0x27 /*0xDC*/, // Right Windows key
	PS2_KEY_APPS         = 0xE0, 0x2F /*0xDD*/, // AppMenu key
	PS2_KEY_POWER        = 0xE0, 0x37 /*0xDE*/, // System Power
	PS2_KEY_SLEEP        = 0xE0, 0x3F /*0xDF*/, // System Sleep
	PS2_KEY_WAKE         = 0xE0, 0x5E /*0xE3*/, // System Wake
	PS2_KEY_WEBSEARCH    = 0xE0, 0x10 /*0xE5*/, // Web Search
	PS2_KEY_WEBFAVORITES = 0xE0, 0x18 /*0xE6*/, // Web Favorites
	PS2_KEY_WEBREFRESH   = 0xE0, 0x20 /*0xE7*/, // Web Refresh
	PS2_KEY_WEBSTOP      = 0xE0, 0x28 /*0xE8*/, // Web Stop
	PS2_KEY_WEBFORWARD   = 0xE0, 0x30 /*0xE9*/, // Web Forward
	PS2_KEY_WEBBACK      = 0xE0, 0x38 /*0xEA*/, // Web Back
	PS2_KEY_MYCOMPUTER   = 0xE0, 0x40 /*0xEB*/, // My Computer
	PS2_KEY_MAIL         = 0xE0, 0x48 /*0xEC*/, // Mail
	PS2_KEY_MEDIASELECT  = 0xE0, 0x50 /*0xED*/   // Media Select
#endif
};

/*
 https://zx-pk.ru/threads/33211-universalnyj-kontroller-ps-2-klaviatury-dlya-kompyuterov-s-matrichnymi-klaviaturami.html
 Xrust PS/2 Keyboard Controller mappings:
  Code    Key   ZX Key
  66      BKSP  [BS]
  (E0),6B LEFT  [Left]
  (E0),72 DOWN  [Down]
  (E0),75 UP    [Up]
  (E0),74 RIGHT [Right]
  76      ESC   [Edit]
  58      CAPS  [Caps lock]
  0D      TAB   [Ext mode]
  41      ,     [,]
  49      .     [.]
  4C      ;     [;]
  52      '     ["]

 Note:
  With Xrust controller firmware, keys with multi-byte scan codes
  handled as keys with single-byte scan codes because of 0xE0 leading byte ignored:

  PS2_KEY_RCONTROL 0xE0, 0x14  "Right Control"              PS2_KEY_LCONTROL 0x14 "Left Control"
  PS2_KEY_DIVIDE   0xE0, 0x4A  "/ on numeric keypad"        PS2_KEY_SLASH    0x4A "/ on main keyboard"
  PS2_KEY_SYSRQ    0xE0, 0x12, "PrintScrn/SysRq"            PS2_KEY_LSHIFT   0x12 "Left Shift"
                   0xE0, 0x7C                               PS2_KEY_MULTIPLY 0x7C "* on numeric keypad"
  PS2_KEY_RMENU    0xE0, 0x11  "Right Alt"                  PS2_KEY_LMENU    0x11 "Left Alt"
  PS2_KEY_UP       0xE0, 0x75  "UpArrow on arrow keypad"    PS2_KEY_NUMPAD8  0x75
  PS2_KEY_LEFT     0xE0, 0x6B  "LeftArrow on arrow keypad"  PS2_KEY_NUMPAD4  0x6B
  PS2_KEY_RIGHT    0xE0, 0x74  "RightArrow on arrow keypad" PS2_KEY_NUMPAD6  0x74
  PS2_KEY_DOWN     0xE0, 0x72  "DownArrow on arrow keypad"  PS2_KEY_NUMPAD2  0x72
  PS2_KEY_DELETE   0xE0, 0x71  "Delete on arrow keypad"     PS2_KEY_DECIMAL  0x71 ". on numeric keypad"
*/

/*
 Taken from https://github.com/leonid-z/zxkeyboard/blob/master/zxps2adapter/zxps2adapter/main.asm

 1 byte scan code for press, prefix F0 for release
 <PS/2 Set 2 Scan Code>, <1st zx key code> <2nd zx key code>
*/
struct scan_code_table_t
{
	uint8_t ps_2_code;
	uint8_t zx_code_1;
	uint8_t zx_code_2;
}
const static scan_code_table[] =
{
	{ PS2_KEY_TAB,        ZX_KEY_CS,   ZX_KEY_SS   }, // Tab -- EXTENDED MODE
	{ PS2_KEY_LSHIFT,     ZX_KEY_CS,   ZX_KEY_NONE }, // Left Shift -- CAPS SHIFT
//	{ PS2_KEY_LCONTROL,   ZX_KEY_SS,   ZX_KEY_NONE }, // Left Ctrl
	{ PS2_KEY_Q,          ZX_KEY_Q,    ZX_KEY_NONE }, // Q
	{ PS2_KEY_1,          ZX_KEY_1,    ZX_KEY_NONE }, // 1
	{ PS2_KEY_Z,          ZX_KEY_Z,    ZX_KEY_NONE }, // Z
	{ PS2_KEY_S,          ZX_KEY_S,    ZX_KEY_NONE }, // S
	{ PS2_KEY_A,          ZX_KEY_A,    ZX_KEY_NONE }, // A
	{ PS2_KEY_W,          ZX_KEY_W,    ZX_KEY_NONE }, // W
	{ PS2_KEY_2,          ZX_KEY_2,    ZX_KEY_NONE }, // 2
	{ PS2_KEY_C,          ZX_KEY_C,    ZX_KEY_NONE }, // C
	{ PS2_KEY_X,          ZX_KEY_X,    ZX_KEY_NONE }, // X
	{ PS2_KEY_D,          ZX_KEY_D,    ZX_KEY_NONE }, // D
	{ PS2_KEY_E,          ZX_KEY_E,    ZX_KEY_NONE }, // E
	{ PS2_KEY_4,          ZX_KEY_4,    ZX_KEY_NONE }, // 4
	{ PS2_KEY_3,          ZX_KEY_3,    ZX_KEY_NONE }, // 3
	{ PS2_KEY_SPACE,      ZX_KEY_SP,   ZX_KEY_NONE }, // Space
	{ PS2_KEY_V,          ZX_KEY_V,    ZX_KEY_NONE }, // V
	{ PS2_KEY_F,          ZX_KEY_F,    ZX_KEY_NONE }, // F
	{ PS2_KEY_T,          ZX_KEY_T,    ZX_KEY_NONE }, // T
	{ PS2_KEY_R,          ZX_KEY_R,    ZX_KEY_NONE }, // R
	{ PS2_KEY_5,          ZX_KEY_5,    ZX_KEY_NONE }, // 5
	{ PS2_KEY_N,          ZX_KEY_N,    ZX_KEY_NONE }, // N
	{ PS2_KEY_B,          ZX_KEY_B,    ZX_KEY_NONE }, // B
	{ PS2_KEY_H,          ZX_KEY_H,    ZX_KEY_NONE }, // H
	{ PS2_KEY_G,          ZX_KEY_G,    ZX_KEY_NONE }, // G
	{ PS2_KEY_Y,          ZX_KEY_Y,    ZX_KEY_NONE }, // Y
	{ PS2_KEY_6,          ZX_KEY_6,    ZX_KEY_NONE }, // 6
	{ PS2_KEY_M,          ZX_KEY_M,    ZX_KEY_NONE }, // M
	{ PS2_KEY_J,          ZX_KEY_J,    ZX_KEY_NONE }, // J
	{ PS2_KEY_U,          ZX_KEY_U,    ZX_KEY_NONE }, // U
	{ PS2_KEY_7,          ZX_KEY_7,    ZX_KEY_NONE }, // 7
	{ PS2_KEY_8,          ZX_KEY_8,    ZX_KEY_NONE }, // 8
	{ PS2_KEY_COMMA,      ZX_KEY_SS,   ZX_KEY_N    }, // ,
	{ PS2_KEY_K,          ZX_KEY_K,    ZX_KEY_NONE }, // K
	{ PS2_KEY_I,          ZX_KEY_I,    ZX_KEY_NONE }, // I
	{ PS2_KEY_O,          ZX_KEY_O,    ZX_KEY_NONE }, // O
	{ PS2_KEY_0,          ZX_KEY_0,    ZX_KEY_NONE }, // 0
	{ PS2_KEY_9,          ZX_KEY_9,    ZX_KEY_NONE }, // 9
	{ PS2_KEY_PERIOD,     ZX_KEY_SS,   ZX_KEY_M    }, // .
	{ PS2_KEY_SLASH,      ZX_KEY_SS,   ZX_KEY_V    }, // /
	{ PS2_KEY_L,          ZX_KEY_L,    ZX_KEY_NONE }, // L
	{ PS2_KEY_SEMICOLON,  ZX_KEY_SS,   ZX_KEY_O    }, // ;
	{ PS2_KEY_P,          ZX_KEY_P,    ZX_KEY_NONE }, // P
	{ PS2_KEY_MINUS,      ZX_KEY_SS,   ZX_KEY_J    }, // -
	{ PS2_KEY_APOSTROPHE, ZX_KEY_SS,   ZX_KEY_P    }, // "
	{ PS2_KEY_EQUALS,     ZX_KEY_SS,   ZX_KEY_L    }, // =
	{ PS2_KEY_CAPITAL,    ZX_KEY_CS,   ZX_KEY_2    }, // Caps Lock
	{ PS2_KEY_RSHIFT,     ZX_KEY_SS,   ZX_KEY_NONE }, // Right Shift -- SYMBOL SHIFT
	{ PS2_KEY_RETURN,     ZX_KEY_ENT,  ZX_KEY_NONE }, // Enter
	{ PS2_KEY_BACK,       ZX_KEY_CS,   ZX_KEY_0    }, // BackSpace - DELETE
	{ PS2_KEY_NUMPAD8,    ZX_KEY_CS,   ZX_KEY_7    }, // Up
	{ PS2_KEY_NUMPAD4,    ZX_KEY_CS,   ZX_KEY_5    }, // Left
	{ PS2_KEY_NUMPAD2,    ZX_KEY_CS,   ZX_KEY_6    }, // Down
	{ PS2_KEY_NUMPAD6,    ZX_KEY_CS,   ZX_KEY_8    }, // Right
	{ PS2_KEY_DECIMAL,    ZX_KEY_SS,   ZX_KEY_M    }, // .
	{ PS2_KEY_ESCAPE,     ZX_KEY_CS,   ZX_KEY_1    }, // Esc - EDIT
	{ PS2_KEY_ADD,        ZX_KEY_SS,   ZX_KEY_K    }, // +
	{ PS2_KEY_SUBTRACT,   ZX_KEY_SS,   ZX_KEY_J    }, // -
	{ PS2_KEY_MULTIPLY,   ZX_KEY_SS,   ZX_KEY_B    }, // *
	{ 0x00, 0x00, 0x00 }
},
// Mapping table for PS/2 set 2 extended scan codes starting with 0xE0.
// Single-byte make code used instead of two byte codes
// in attempt to make things faster and simpler.  
scan_code_table_E0[] =
{
//	{ PS2_KEY_LCONTROL /*PS2_KEY_RCONTROL*/,  ZX_KEY_SS,   ZX_KEY_NONE }, // Left Ctrl
	{ PS2_KEY_NUMPAD8 /*PS2_KEY_UP*/,         ZX_KEY_CS,   ZX_KEY_7}, // Up
	{ PS2_KEY_NUMPAD4 /*PS2_KEY_LEFT*/,       ZX_KEY_CS,   ZX_KEY_5}, // Left
	{ PS2_KEY_NUMPAD2 /*PS2_KEY_DOWN*/,       ZX_KEY_CS,   ZX_KEY_6}, // Down
	{ PS2_KEY_NUMPAD6 /*PS2_KEY_RIGHT*/,      ZX_KEY_CS,   ZX_KEY_8}, // Right
	{ PS2_KEY_SLASH /*PS2_KEY_DIVIDE*/,       ZX_KEY_SS,   ZX_KEY_V}, // /
	{ PS2_KEY_RETURN /*PS2_KEY_NUMPADENTER*/, ZX_KEY_ENT,  ZX_KEY_NONE}, // Enter
	{ PS2_KEY_NUMPAD9 /*PS2_KEY_PRIOR*/,      ZX_KEY_CS,   ZX_KEY_3 }, // PageUp
	{ PS2_KEY_NUMPAD3 /*PS2_KEY_NEXT*/,       ZX_KEY_CS,   ZX_KEY_4 }, // PageDown
	{ 0x00, 0x00, 0x00 }
};

PS2KeyRaw keyboard;

void setup()
{
	//Инициализация портов
	pinMode(AX0, OUTPUT);   //AX0
	pinMode(AX1, OUTPUT);   //AX1
	pinMode(AX2, OUTPUT);   //AX2
	pinMode(AX3, OUTPUT);   //AX3
	pinMode(AY0, OUTPUT);   //AY0
	pinMode(AY1, OUTPUT);   //AY1
	pinMode(AY2, OUTPUT);   //AY2
	pinMode(RSTMT, OUTPUT); //RES
	pinMode(CSMT, OUTPUT);  //CS
	pinMode(DATMT, OUTPUT); //DAT
	pinMode(STBMT, OUTPUT); //STB

	//Инициализация клавиатуры
	keyboard.begin( DATAPIN, IRQPIN );

	//Инициализация MT8816
	SetAddr(0);
	digitalWrite(RSTMT, LOW);
	digitalWrite(CSMT, LOW);
	digitalWrite(DATMT, LOW);
	digitalWrite(STBMT, LOW); //инициализация
	digitalWrite(CSMT, HIGH); //выбор чипа
	digitalWrite(RSTMT, HIGH);
	digitalWrite(RSTMT, LOW); //сброс
	digitalWrite(CSMT, LOW);

	SetAddr(ZX_KEY_CS);
	SetKey(LOW);
}

void SetAddr(uint8_t addr)
{
	digitalWrite(AX0,bitRead(addr,0));
	digitalWrite(AX1,bitRead(addr,1));
	digitalWrite(AX2,bitRead(addr,2));
	digitalWrite(AX3,bitRead(addr,3));
	digitalWrite(AY0,bitRead(addr,4));
	digitalWrite(AY1,bitRead(addr,5));
	digitalWrite(AY2,bitRead(addr,6));
}

void SetKey(boolean data){
	digitalWrite(CSMT, HIGH); //выбор чипа
	digitalWrite(STBMT, HIGH); //строб on
	digitalWrite(DATMT, data); //данные
	digitalWrite(STBMT, LOW); //строб off
	digitalWrite(CSMT, LOW);
}

volatile boolean state = HIGH;
  
void loop()
{
	if( keyboard.available() )
	{
		int c = keyboard.read(); //чтение кода
		switch (c)
		{
			case 0xE0: //если считался префикс 0xE0 (2-byte extended key code prefix)
				break;
			case 0xF0: //если считался префикс 0xF0 (отпускание клавиши)
				state = LOW;
				break;
			default:
				const struct scan_code_table_t *entry = scan_code_table; // (code_0 == 0xE0) ? scan_code_table_E0 : scan_code_table;

				// Linear find with O(n). Can be pre-sorted offline and processes with O(log2n),
				// or sparsed array can be created with at least 0x7F(0x83) entries for O(1).
				while (entry->ps_2_code)
				{
					if(entry->ps_2_code == c)
					{
						if(entry->zx_code_1 != ZX_KEY_NONE)
						{
							SetAddr(entry->zx_code_1);
							SetKey(state);
						}

						if(entry->zx_code_2 != ZX_KEY_NONE)
						{
							SetAddr(entry->zx_code_2); // Extended 58-key keyboard key
							SetKey(state);
						}

						state = HIGH;

						break;
					}
					entry++;
				}
		}
	}
}

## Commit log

2023-12-29 Initial commit.
    Implement PS/2 keyboard controller with MT8816 and ATmega168.
    Implement SCART RGB TV out.
    Implement Kempston to Sega Mega Drive gamepad adapter.
    Connectors internal:
    Keyboard, ISP, FDD power, Kempston In, Audio In,
    Connectors external:
    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
    [Pentagon128_InterfaceBoard.kicad_pcb, Pentagon128_InterfaceBoard.kicad_sch]
2023-12-29 Add 5.5x2.1mm 5V DC external power connector.
    [Pentagon128_InterfaceBoard.kicad_pcb, Pentagon128_InterfaceBoard.kicad_sch]
2023-12-31 Add 5V DC IN markings.
    [Pentagon128_InterfaceBoard.kicad_pcb]
2024-01-01 Interface PCB dimensions based on real main PCB measurements. Replace main PCB edge from gerbers to custom placeholder. Replace vias with mounting holes, correct placement. Add mounting hole between 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
    [Pentagon128_InterfaceBoard.kicad_pcb]
2024-01-01 Arrange modules in schematic.
    [Pentagon128_InterfaceBoard.kicad_sch]
2024-01-01 Set mounting holes clearance. Fix edge cuts, move reference to user drawings layer.
    [Pentagon128_InterfaceBoard.kicad_pcb]
2024-01-04 Intermediate variant based on review feedback. Added SN74LS07 oped drain buffers for switch matrix data lines output (questionable). Changes based on "AVR Microcontroller Hardware Design Consideratio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
    [Pentagon128_InterfaceBoard.kicad_pcb, Pentagon128_InterfaceBoard.kicad_sch]
2024-01-05 Remove SN74LS07 data bus buffer from schematic and PCB, considering MT8816 switches as switches connecting logical "0" from address bus line to keyboard data bus pulled to "1" (VCC) via pull-up resis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
    Re-enumerate capacitors.
    Remove electrolytic capacitors from board.
    [Pentagon128_InterfaceBoard.kicad_pcb, Pentagon128_InterfaceBoard.kicad_sch]
2024-01-06 Replace MT8816 pin solder footprint with PLCC-44_THT-Socket.
    [Pentagon128_InterfaceBoard.kicad_pcb, Pentagon128_InterfaceBoard.kicad_sch]
2024-01-06 Extend board height from 57.4 mm to 60 mm.
    [Pentagon128_InterfaceBoard.kicad_pcb]
2024-01-06 Move KEMPSTON_IN connector closer to Sega Mega Drive Controller connector. Orientation to better fit connecting flat cable.
    [Pentagon128_InterfaceBoard.kicad_pcb]
2024-01-06 Move PS/2 keyboard controller down. Align EXT_KEYBOARD connector markings. Fix DRC errors. Additional fill exclude zones.
    [Pentagon128_InterfaceBoard.kicad_pcb]
2024-01-07 Add VGA output based on @Alex_Eburg's https://github.com/AlexEkb4ever/ZX_RGBI2VGA-HDMI Repace Raspberry Pi Pico with RP2040-Zero. Add 9 pin RGBI header for Pentagon 2023. Add RP2040-Zero symbol and f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
    [Pentagon128_InterfaceBoard.kicad_pcb, Pentagon128_InterfaceBoard.kicad_sch]
2024-01-07 Add missing pico_RGB_TO_VGA.kicad_sch. Add 1 dummy pin to RGBI connector. Rename KSI -> KS, SSI -> SS.
    [Pentagon128_InterfaceBoard.kicad_pcb, Pentagon128_InterfaceBoard.kicad_sch, pico_RGB_TO_VGA.kicad_sch]
2024-01-08 Add comment for RGBI connector dummy pin.
    [pico_RGB_TO_VGA.kicad_sch]
2024-01-08 Move labels outside board edge from F.Silkscreen to User.Drawings layer.
    [Pentagon128_InterfaceBoard.kicad_pcb]
2024-01-08 Remove main board mockups from PCB.
    [Pentagon128_InterfaceBoard.kicad_pcb]
2024-01-08 Remove DIN 41612 connector outline from B.Silkscreen.
    [Pentagon128_InterfaceBoard.kicad_pcb]
2024-01-08 Add gerber and drill files.
    [Pentagon128_InterfaceBoard-B_Cu.gbr, Pentagon128_InterfaceBoard-B_Mask.gbr, Pentagon128_InterfaceBoard-B_Paste.gbr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]
2024-02-21 Move FDD Power connector 2 mm off board edge.
    [Pentagon128_InterfaceBoard.kicad_pcb]
2024-03-03 Add "CUI Devices SJ1-3535 3.5 mm Right-Angle Stereo Jack, 5 Pin PCB Mount, Threaded w/ Nut" 3D model. Source: https://www.cuidevices.com/product/resource/3dmodel/sj1-3535
    [Pentagon128_InterfaceBoard.kicad_pcb]
2024-09-03 Replace incorrect RP2040-Zero symbol and footprint from https://github.com/CountParadox/RP2040-Zero-Kicad with fixed from https://github.com/VoxelTek/RP2040-Zero-Kicad commit:af76b901b5ae1c112921783d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
2024-09-03 Critical error fixed: connect RP2040-Zero GND and VCC to pins 31/32 instead of 29/28.
    [Pentagon128_InterfaceBoard.kicad_pcb, pico_RGB_TO_VGA.kicad_sch]
2024-09-04 Update gerber and drill files.
    [Pentagon128_InterfaceBoard-B_Cu.gbr, Pentagon128_InterfaceBoard-B_Mask.gbr, Pentagon128_InterfaceBoard-B_Paste.gbr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]
2025-11-28 Replace switch-case for ZX extended keyboard keys with two-keys lookup table.
    [Spectrum128.ino]
2025-11-28 Return back global volatile for key state variable. Fixed keyboard lock issue.
    [Spectrum128.ino]
